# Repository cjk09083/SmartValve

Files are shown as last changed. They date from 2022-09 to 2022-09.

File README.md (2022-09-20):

# SmartValve
<div>





</div>

## LoRa 통신기반 자가발전형 원격 수로 모니터링 시스템

<div align="center">
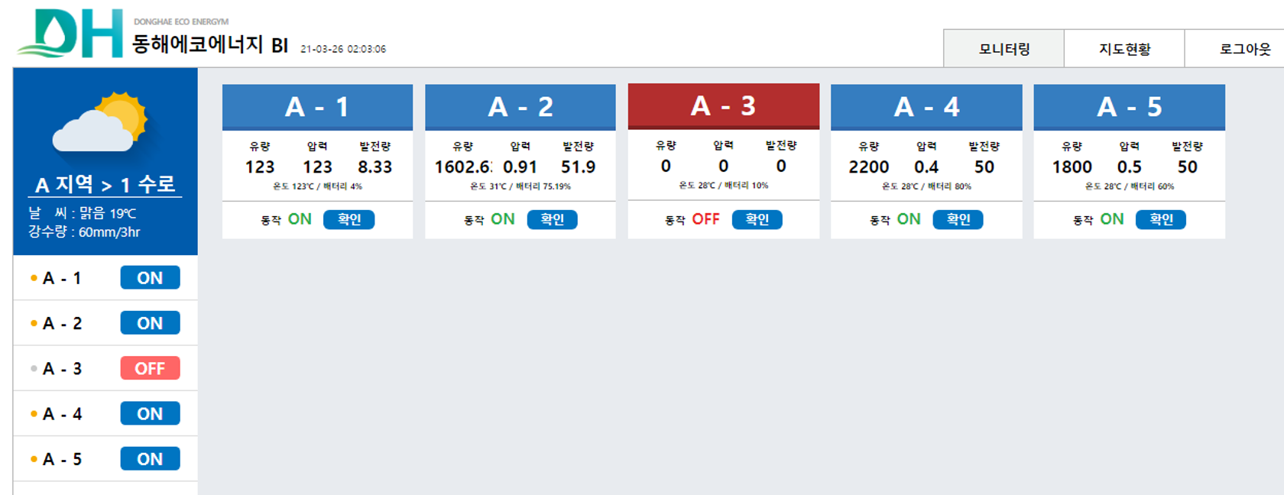
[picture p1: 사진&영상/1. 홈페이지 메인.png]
&nbsp;  
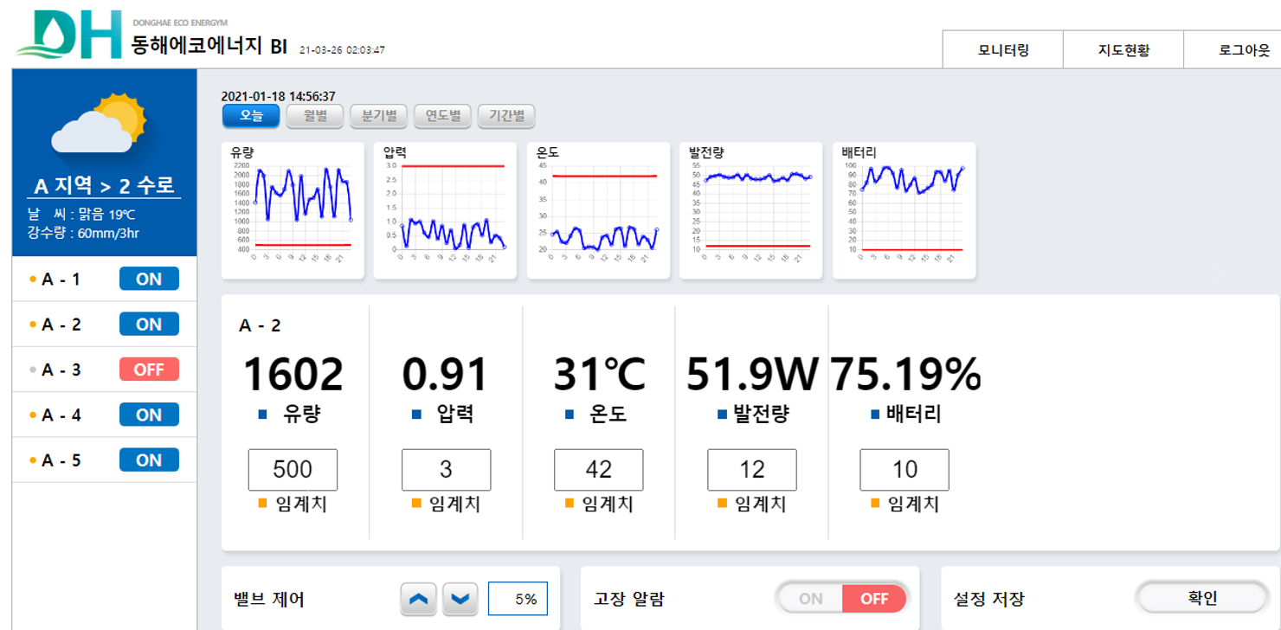
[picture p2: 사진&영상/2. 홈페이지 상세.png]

</div></br>

## 목적
- 수로에 흐르는 물을 이용해 자가발전 
- 수로와 사무실간의 LoRa를 이용한 무선통신을 연결하고 데이터 송수신 하는 시스템 
- 수로의 상태를 홈페이지에서 모니터링하고 홈페이지에서 수로를 원격 제어

## 담당 
- 모니터링 홈페이지 (HTML, PHP, JavaScript)  
- 아두이노의 수로 모터 제어와 센서링 정보 무선 통신 (LoRa, WiFi)
- KC 인증 (전자파적합성인증 - 한국전자통신연구원)
- 소수력 발전을 위한 충방전 회로 설계 

## 기능

### 1. 수로에서 흐르는 물로 발전기를 돌려 아두이노와 센서들을 동작시킬 전력 충전
 - 수로 내에 수차와 발전기를 연결, 발생하는 전력을 변환하여 배터리에 충전
<div align="center">
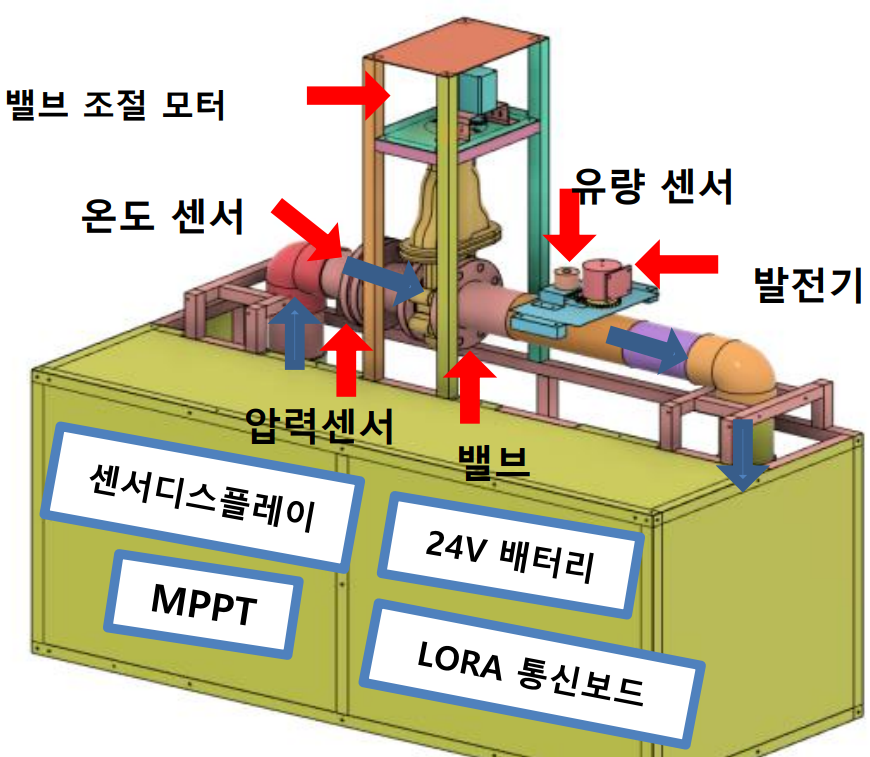
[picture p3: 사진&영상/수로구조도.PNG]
&nbsp;  
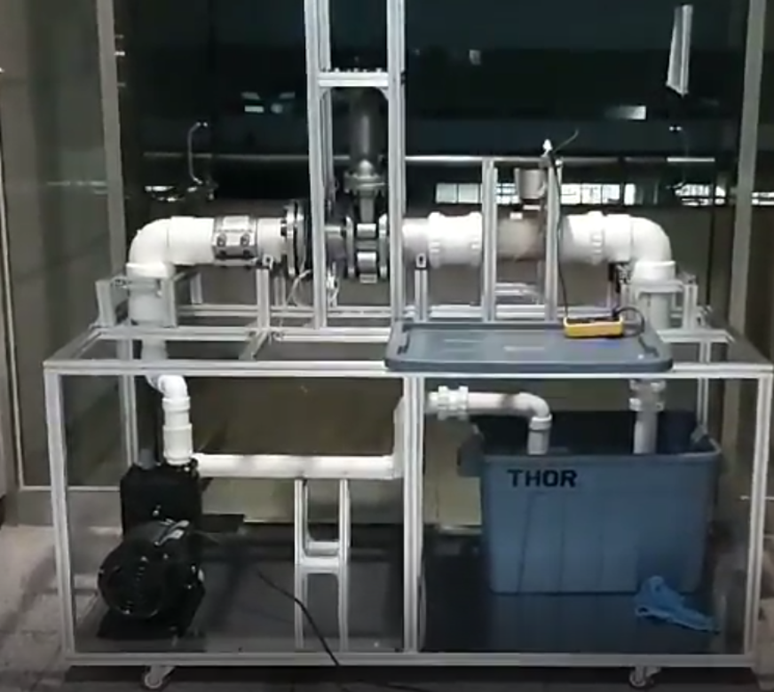
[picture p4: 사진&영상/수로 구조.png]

</div></br>

### 2. 수로에서 측정한 정보를 서버와 연동
 - 수로에 설치된 아두이노와 사무실에 설치된 아두이노간의 LoRa 통신 연결 (무자격으로 사용 가능한 923.1MHz 대역 사용)
 - 사무실에 설치된 아두이노에서 서버로 정보 업로드 (Wifi HTTP)
 - 홈페이지에서 밸브 OPEN량을 0~100%로 조절하면 통신이 역순으로 수로에 도달해 수로의 수문에 달린 모터 제어 
 
영상) 수로 밸브를 50%-> 1% 로 제어 (사진&영상/밸브 제어 50 to 1.mp4)
<div align="center">

</div></br>

### KC 인증 (전자파적합성인증) - 제어보드 / 전자파테스트 / 충격테스트
<div align="center">
 &nbsp;  
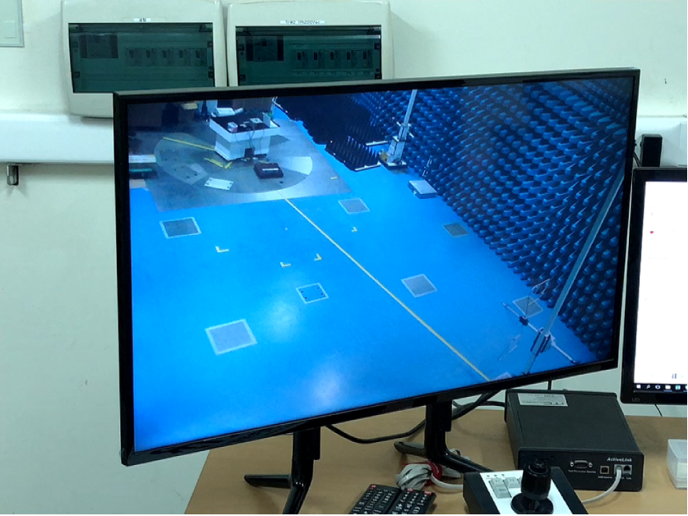
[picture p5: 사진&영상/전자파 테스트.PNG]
&nbsp;  
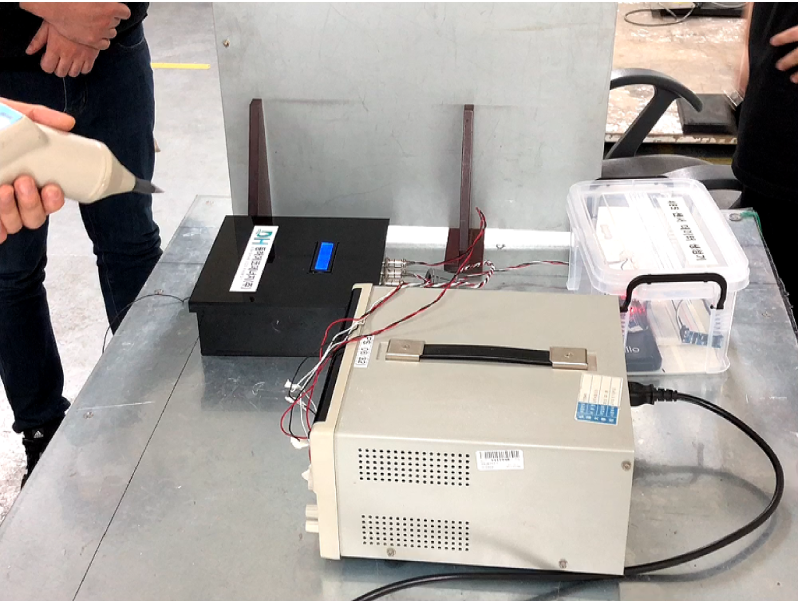
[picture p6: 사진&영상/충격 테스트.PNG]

</div></br>

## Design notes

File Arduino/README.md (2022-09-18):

# Arduino 파일 설명

485_gen : (아두이노 우노) 485 센서 데이터 생성기, 5초 간격으로 3개의 값이 순환변경됨

Nano_suro : (아두이노 나노) 전압센서를 통해 측정한 발전량, 배터리량을 Lora 보드에게 전송해줌

LoRa_Gateway : (Lora32) 사무실에 설치되는 Lora 게이트웨이, wifi사용

LoRa_suro : (Lora32) 수로에 설치되는 제품속 Lora 단말기, KC인증 대상

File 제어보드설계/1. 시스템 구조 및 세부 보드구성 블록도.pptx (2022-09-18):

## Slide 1

시스템 블록도

모터

모터 드라이버

USER

SERVER

배터리

WIFI

WIFI

수로

NANO

LORA

센서
(온도/유량/압력)

LCD

GATE
WAY

Raspberry Pi
(고장 진단)

LORA 통신

RS-485 통신

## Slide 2

보드 블록도

수로 발전기

GND

MPPT

GND

태양광 발전기

3상 컨버터

A상

B상

C상

릴레이

릴레이

전압 센서

GND

5V

GND

GND

5V

LORA board

발전량

GND

24V

Motor driver

배터리

컨버터

5V

GND

5V

회전 방향

펄스

GND

전압 센서

GND

RX

TX

RS485 to
UART

GND

A

B

압력 센서

GND

GND

유량 센서

GND

5V

Arduino nano board

온도 센서

발전량

배터리 잔량

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
3.3V

20~24V

배터리 잔량

배터리

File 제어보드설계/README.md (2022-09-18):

# 시스템 구조

## 시스템 블록도
<div align="center">
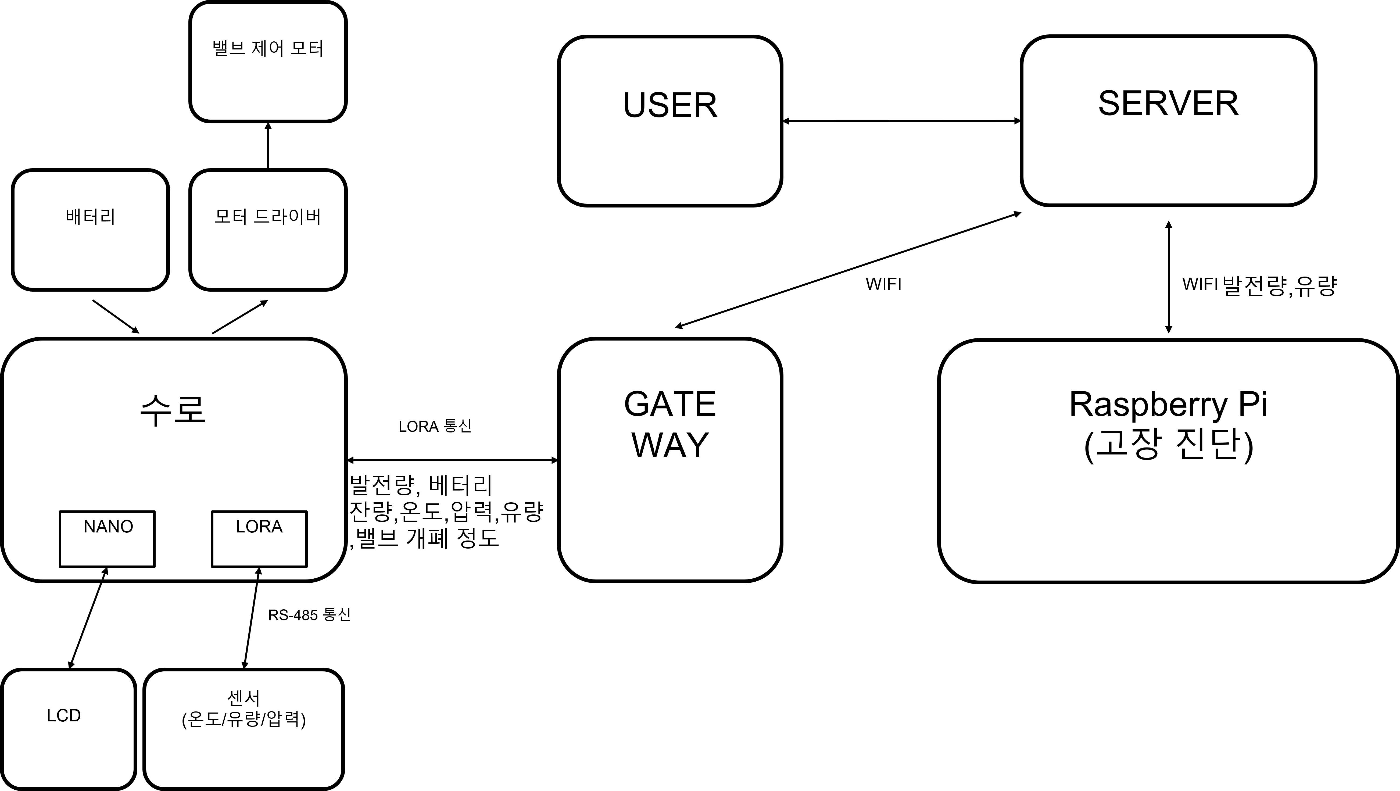
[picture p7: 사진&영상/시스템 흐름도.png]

</div></br>

1. 수로의 메인보드와 게이트웨이는 동일한 LoRa 통신 보드를 사용하여 통신한다.

2. 수로에서 게이트웨이로 온도&유량&압력 센서값과 배터리잔량, 발전량, 밸브값(닫힌 정도)을 전송한다. </br>
  게이트웨이에서는 USER가 조작한 밸브 제어명령을 수로에 전송한다.
  
3. 게이트웨이는 각 수로에서 모인 수로 데이터를 WiFi 통신으로 서버에 축적한다.

4. 라즈베리파이 보드는 일정 시간마다 서버에서 수로 데이터를 가져와 인공지능 고장 진단을 수행하고 진단 결과를 다시 서버에 전송한다.

5. 유저는 홈페이지 GUI 형태로 서버에 축적된 데이터를 확인하고 필요해 각 수로의 밸브값을 제어할 수 있다.

## 보드 블록도
<div align="center">
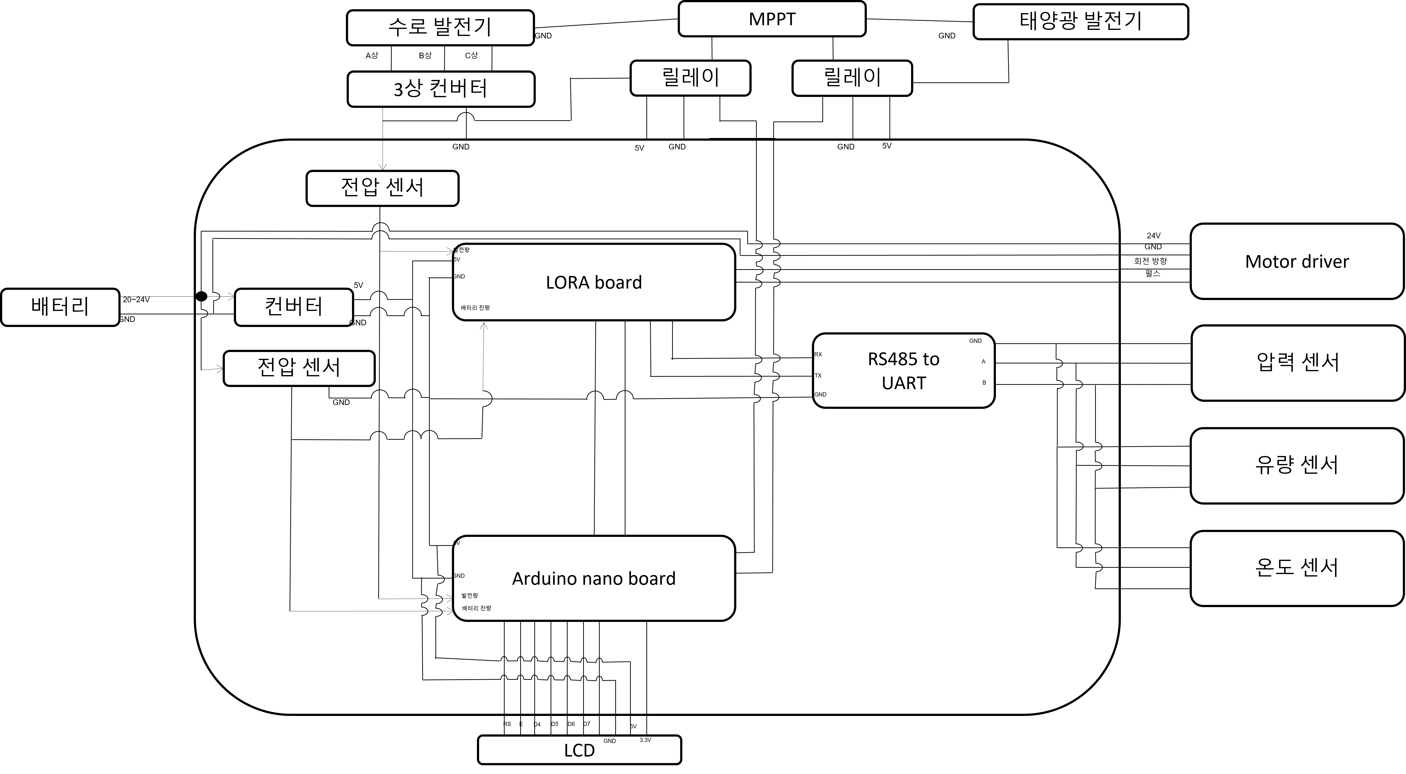
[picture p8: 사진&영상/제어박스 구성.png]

</div></br>

1. 배터리(20~24V)의 전압이 모터드라이브에 공급되고 컨버터를 통해 5V로 다운되어 Nano 보드와 LoRa 보드에 공급된다. 

2. 보드의 LoRa보드에서 RS485통신을 통해 압력&유량&온도 센서값을 가져오고 수로 발전기의 발생 전압과 배터리 전압을 전압센서를 통해 가져온다. </br>
  이후 수집한 센서값과 전압값을 LoRa통신 안테나를 통해 게이트웨이 LoRa보드에게 전송한다.
  
3. Nano 보드는 전압센서을 통해 측정한 배터리 잔량과 발전량을 가져와 LCD 디스플레이에 출력한다. </br>
  또한 릴레이 모듈을 제어하여 수로 발전기가 동작할때는 수로 발전기와 배터리를 연결하고 그 외에는 태양광 발전기와 배터리를 연결하여 배터리를 충전시킨다.
  
4. 게이트웨이에서 밸브 제어 명령이 도착할 경우 LoRa보드에서 현재의 밸브값과 제어 명령이 지령하는 밸브값을 비교하여 필요한 횟수만큼 스텝모터를 회전시킨다.

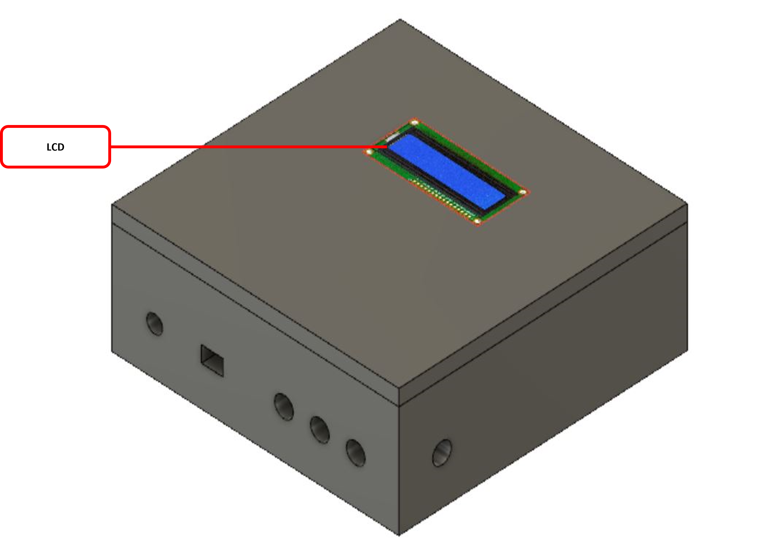
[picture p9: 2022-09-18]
사진&영상/제어박스 외부.png

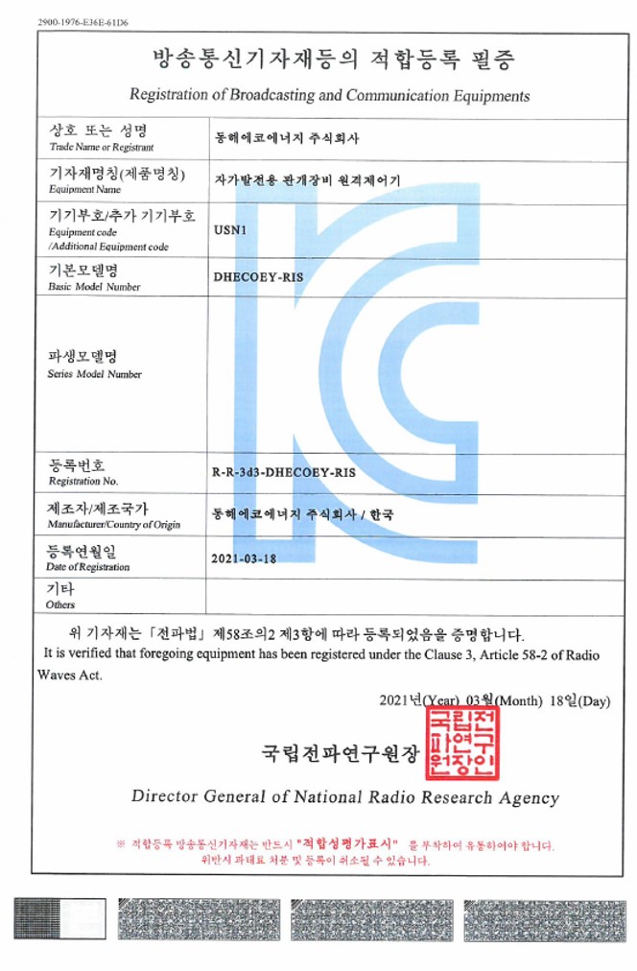
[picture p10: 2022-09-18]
사진&영상/수로 KC 인증.jpg

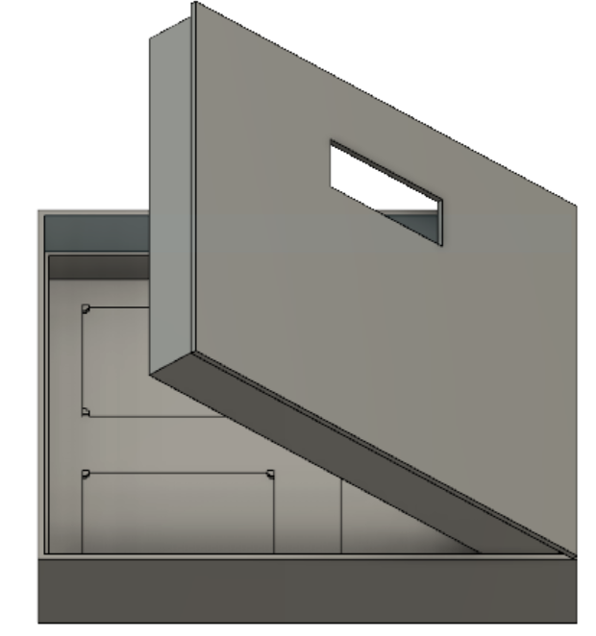
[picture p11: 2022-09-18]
제어보드설계/3. 보드 케이스 3D 디자인/2 전면부 OPEN시 (측면부 커넥터 부분 디자인은 미정).png

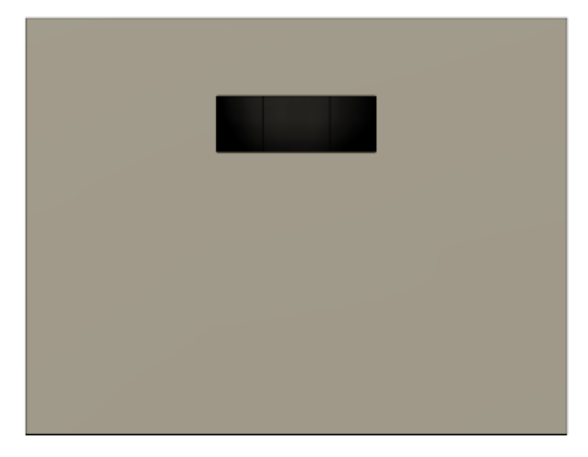
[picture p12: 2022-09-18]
제어보드설계/3. 보드 케이스 3D 디자인/1 전면부(구멍에는 LCD).png

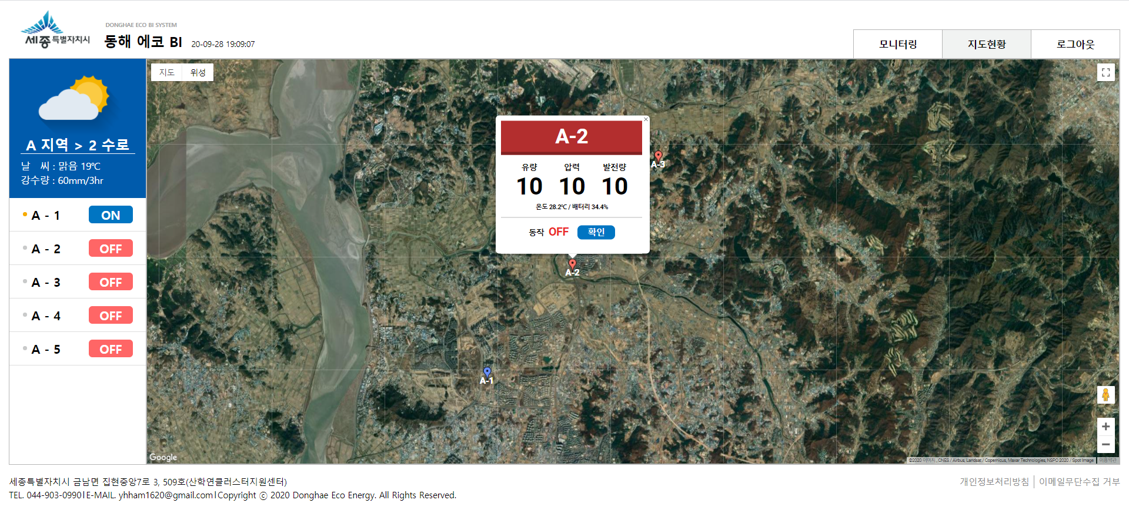
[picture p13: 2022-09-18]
사진&영상/3. 홈페이지 지도.png

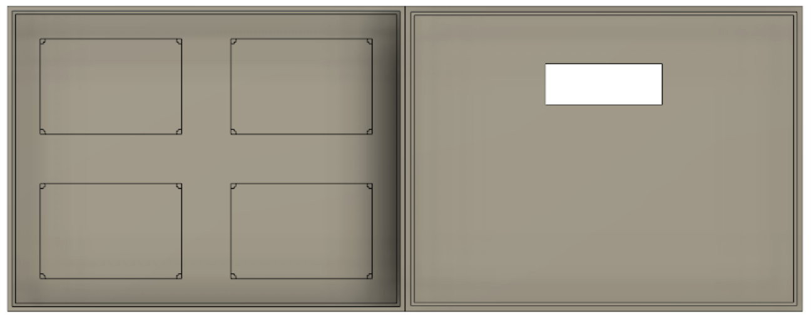
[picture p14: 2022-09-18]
제어보드설계/3. 보드 케이스 3D 디자인/3 아랫부분과 윗부분 나란히 (빵판 4개를 간격을 두고 배치).png

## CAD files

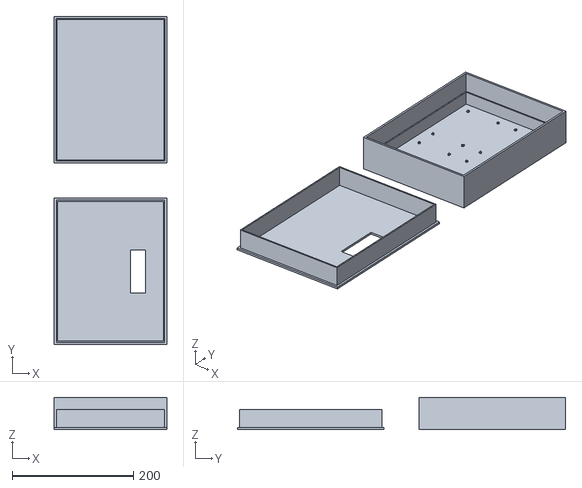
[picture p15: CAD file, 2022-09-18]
제어보드설계/3. 보드 케이스 3D 디자인/케이스 도면.stl
186.0 x 542.0 x 53.0

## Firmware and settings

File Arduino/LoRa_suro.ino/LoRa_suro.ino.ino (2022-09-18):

//백업용 파일 20210307//
#include <SPI.h>
#include <LoRa.h>
#include <Wire.h>  
#include "SSD1306.h" 
#include <EEPROM.h>
#include <LiquidCrystal_I2C.h>

#define SCK     5    // GPIO5  -- SX1278's SCK
#define MISO    19   // GPIO19 -- SX1278's MISnO
#define MOSI    27   // GPIO27 -- SX1278's MOSI
#define SS      18   // GPIO18 -- SX1278's CS
#define RST     14   // GPIO14 -- SX1278's RESET
#define DI0     26   // GPIO26 -- SX1278's IRQ(Interrupt Request)
#define BAND  923100000 // 923.1 MHz

#define ENA     23   // GPIO21 -- Valve ENA
#define DIR     12   // GPIO12 -- Valve DIR
#define PUL     13   // GPIO13 -- Valve PUL

//#define TRIG    25   // GPIO39 -- sonic TRIG
//#define ECHO    34   // GPIO38 -- sonic ECHO

//#define PIN_SDA 21
//#define PIN_SCL 22

#define PIN_BAT 34
#define PIN_CHA 35

uint8_t T[] = {0x03, 0x04, 0x03, 0xE8, 0x00, 0x02, 0xF0, 0x59};
uint8_t P[] = {0x01, 0x04, 0x00, 0x00, 0x00, 0x02, 0x71, 0xCB};
uint8_t F[] = {0x02, 0x04, 0x03, 0xE9, 0x00, 0x02, 0xA0, 0x48};


//uint8_t T[] = {0x03};

int data[10];

unsigned long total_step = 48 * 50 * 80; // 48바퀴 * * 80스텝?
unsigned long full_step = 48 * 5000 * 80;

int step_du = 15;           // 펄스 길이 [us]
int step_delay = 15;
        
int id = 1;
unsigned long counter = 0;
unsigned int send_flag = 0;
long mot_step = 0;

int close_dir = 1; //명령어 d가 닫기, a가 열기
int open_dir = 0;

unsigned long ctn_ms = 0;
int   mot_dir = 1, mot_ena = 0;
double valve_data = 0;
float temp = 0, pressure = 0, flow = 0, distance=0, bat = 0, charge = 0;
float temp_total = 0, pressure_total = 0, flow_total = 0, bat_total = 0, charge_total = 0;

//SSD1306 display(0x3c, 21, 22);
String rssi = "RSSI --";
String packSize = "--";
String packet ;
String mot_data = "Valve stop";
//==================================================
//OLED pins to ESP32 GPIOs via this connecthin:
//OLED_SDA -- GPIO4
//OLED_SCL -- GPIO15
//OLED_RST -- GPIO16

SSD1306  display(0x3c, 4, 15);
//HardwareSerial Serial2(2);
LiquidCrystal_I2C lcd(0x27,16,2);  // set the LCD address to 0x27 for a 16 chars and 2 line display



////////////////////////////////////////
/////////// functions///////////////////
////////////////////////////////////////
void drawFontFaceDemo();
String readSerial();
String readSerial2();
void cbk(int packetSize);
void DisplaySetup();
void ValveSetup();
void break_str(String str);
float checkT();
float checkP();
float checkF();
float checkB();
float checkC();
void lcd_set();   //lcd 값 세팅 

float wire_arduino();


////////////////////////////////////////
/////////// setup & loop ///////////////
////////////////////////////////////////

void setup() {
  if(id==1){
    total_step = 1 * 50 * 80; // 48바퀴 * * 80스텝?
    full_step = 1 *5000 * 80;
    step_du = 20;
    step_delay = 50;
  }
  //DisplaySetup();
  ValveSetup();
//  pinMode(ENA, OUTPUT);
  pinMode(DIR, OUTPUT);
  pinMode(PUL, OUTPUT);

  Wire.begin();
  lcd.init();                      // initialize the lcd 
  lcd.backlight();
  lcd_set();
  Serial.begin(9600);
//  Serial2.begin(9600);

  //Serial1.begin(9600,SERIAL_8N1, 22, 36); //Baud rate, parity mode, RX, TX
  Serial2.begin(9600,SERIAL_8N1, 23, 17); //Baud rate, parity mode, RX, TX

//  while (!Serial);
  Serial.println();
  Serial.println("LoRa Sender Test");
  
  SPI.begin(SCK,MISO,MOSI,SS);
  LoRa.setPins(SS,RST,DI0);
  if (!LoRa.begin(BAND)) {
    Serial.println("Starting LoRa failed!");
    while (1);
  }
  LoRa.setTxPower(14);

  //LoRa.onReceive(cbk);
//  EEPROM.write(10, 10);
//  EEPROM.commit();

  EEPROM.begin (255);
//  EEPROM.write(1, 4);
  delay(10);
  valve_data = EEPROM.read(1);
  mot_step = valve_data * full_step / 100;
  Serial.print("Init Valve : ");
  Serial.println(valve_data);
  Serial.print(", Steps : ");
  Serial.println(mot_step);
  LoRa.receive();
  
  Serial.println("init ok");

}


void loop() {
  int packetSize = LoRa.parsePacket();
  if (packetSize) { cbk(packetSize);  }

  String str;
  if (Serial.available()){
    str = readSerial();   
    Serial.println(str); 
    break_str(str);   
  }
  
//  if (Serial2.available()){
//    readSerial2();  
//  }
  
  if(ctn_ms++> 100){
    send_flag++;
       
    digitalWrite(DIR, mot_dir);    
    Serial.print("Valve DIR : ");
    Serial.println(mot_dir);
//    digitalWrite(ENA, HIGH);
    mot_ena = 0;  

    temp = checkT();
    temp_total += temp;
    delay(10);
    pressure = checkP();
    pressure_total += pressure;
    delay(10);
    flow = checkF();
    flow_total += flow;
    Serial.print("Temp : ");
    Serial.print(temp);
    Serial.print("(");
    Serial.print(temp_total/send_flag);

    Serial.print("), Pressure : ");
    Serial.print(pressure);
    Serial.print("(");
    Serial.print(pressure_total/send_flag);
    
    Serial.print("), Flow : ");
    Serial.print(flow);
    Serial.print("(");
    Serial.print(flow_total/send_flag);
    Serial.println(")");

    valve_data = mot_step * 100 / full_step;
    Serial.print("Valve : ");
    Serial.print(valve_data);
    EEPROM.write(1, valve_data);
    EEPROM.commit();

    wire_arduino();
    
    //bat = checkB();
    bat_total += bat;
    Serial.print(", Battery : ");
    Serial.print(bat);
    Serial.print("(");
    Serial.print(bat_total/send_flag);
    
    //charge = checkC(); 
    charge_total += charge;
    Serial.print("), Charge : ");
    Serial.print(charge);
    Serial.print("(");
    Serial.print(charge_total/send_flag);
    Serial.print(") ");
    
    lcd_set();
    
    // send packet
    if (send_flag > 3){
      lcd.init();
      lcd_set();
      temp = temp_total / send_flag;
      pressure = pressure_total / send_flag;
      flow = flow_total / send_flag;
      bat = bat_total / send_flag;
      charge = charge_total / send_flag;
      String senddata = "d"+String(id)+"c"+String(counter)+"t"+String(temp)
      +"p"+String(pressure)+"f"+String(flow)+"v"+String(valve_data)+"b"+String(bat)+"h"+String(charge)+"e";
      LoRa.beginPacket();  
      LoRa.print(senddata);
      LoRa.endPacket();
      
      Serial.print("Send : ");
      Serial.println(senddata);
      //drawFontFaceDemo();     
      temp_total = 0; pressure_total = 0; flow_total = 0; bat_total = 0; charge_total = 0;
      counter++; 
      send_flag = 0;        
    } else {  
      Serial.print("Send_flag : ");
      Serial.println(send_flag);
    }
    ctn_ms=0;
  }

  ctn_ms++;
//  Serial.println(ctn_ms);
  
  delay(1);                       

}


///////////////////////////////////// ///
/////////// functions///////////////////
////////////////////////////////////////
void break_str(String str){
  
  if (str.startsWith("a")) {       
      Serial.println("Valve close");   
      mot_data = "Valve close";
      mot_dir = close_dir;  
      mot_ena = 1;
      digitalWrite(DIR, mot_dir); 
      Serial.print("Valve Dir :");   
      Serial.println(mot_dir);   
      delay(100);
//      digitalWrite(ENA, LOW);  
      delay(10);
      for (int i = 0; i < total_step; i++){
        digitalWrite(PUL, HIGH);    
        delayMicroseconds(step_du);                     
        digitalWrite(PUL, LOW);    
        delayMicroseconds(step_delay);  
      }
      mot_step -= total_step;
      valve_data = mot_step * 100 / full_step;
      Serial.print("Valve : ");
      Serial.print(valve_data); 
      Serial.println(" Turn end");       
      EEPROM.write(1, valve_data);
      EEPROM.commit();
      delay(10);
//      digitalWrite(ENA, HIGH);  
      ctn_ms = 0;
    } else if (str.startsWith("d"))  {   
      Serial.println("Valve open");  
      mot_data = "Valve open"; 
      mot_dir = open_dir;
      mot_ena = 1;
      digitalWrite(DIR, mot_dir);  
      Serial.print("Valve Dir :");   
      Serial.println(mot_dir);    
      delay(100);
//      digitalWrite(ENA, LOW);  
      delay(10);
      for (int i = 0; i < total_step; i++){
        digitalWrite(PUL, HIGH);    
        delayMicroseconds(step_du);                     
        digitalWrite(PUL, LOW);    
        delayMicroseconds(step_delay);  
      }
      mot_step += total_step;
      valve_data = mot_step * 100 / full_step;
      Serial.print("Valve : ");
      Serial.print(valve_data); 
      Serial.println(" Turn end"); 
      EEPROM.write(1, valve_data);
      EEPROM.commit();
      delay(10);
//      digitalWrite(ENA, HIGH);  
      ctn_ms = 0;
    } else if (str.startsWith("s"))  {   
      Serial.println("Valve stop");
      mot_data = "Valve stop";   
      EEPROM.write(1, mot_step);
      EEPROM.commit();
//      digitalWrite(ENA, HIGH);
      mot_ena = 0;  
      mot_step = 0;
    } else if (str.startsWith("p"))  {   
        int diff_value = 5;
        Serial.println("Valve close");  
        mot_data = "Valve close"; 
        mot_dir = close_dir;
        mot_ena = 1;
        digitalWrite(DIR, mot_dir);  
        Serial.print("Valve Dir :");   
        Serial.println(mot_dir);   
        Serial.print("Need turns :");   
        Serial.println(diff_value);  
        delay(100);
//        digitalWrite(ENA, LOW);  
        delay(10);
        for (int i = 0; i < diff_value; i++){
         for (int j = 0; j < total_step; j++){
            digitalWrite(PUL, HIGH);    
            delayMicroseconds(step_du);                     
            digitalWrite(PUL, LOW);    
            delayMicroseconds(step_delay);  
          }
          mot_step += total_step;
          valve_data = mot_step * 100 / full_step;
          Serial.print("mot_step : ");   
          Serial.print(mot_step);
          Serial.print(", Valve1 : ");   
          Serial.println(valve_data);
        }
        Serial.println("Turn end");  
        EEPROM.write(1, valve_data);
        EEPROM.commit();
        delay(10);
//        digitalWrite(ENA, HIGH);  
        ctn_ms = 0;
  }
  
}

void drawFontFaceDemo() {
    display.clear();
    String s="ID:"+String(id)+" Send: ";
    s=s+counter;
    String sen = "T:"+String(int(temp))
    +" P:"+String(int(pressure))+" F:"+String(int(flow));
    display.drawString(0, 0, s);
    display.drawString(0, 20, mot_data);
    display.drawString(0, 40, sen);
    display.display();
}

String readSerial(){   
   String str = "";   
   char ch;   
    while( Serial.available() > 0 )   
    {   
      ch = Serial.read();   
      str.concat(ch);   
      delay(10);  
    }   
    return str;     
}   


String readSerial2(){   
   String str = "";   
   char ch;   
   int ct = 0;
   Serial.print("Recived : "); 
    while( Serial2.available() > 0 )   
    {   
      ch = Serial2.read();   
      str.concat(ch);
      Serial.print(" "); 
      Serial.print(ch,HEX); 
      data[ct] = (int) ch; 
      if(data[ct] < 0){
        data[ct] = 256 - (int)(0xFFFFFF - ch);
       }
      ct++;
      delay(10);  
    }   
    Serial.println();
    return str;     
}   


void cbk(int packetSize) {
  packet ="";
  packSize = String(packetSize,DEC);

  for (int i = 0; i < packetSize; i++) { packet += (char) LoRa.read(); }

  if (packet.startsWith("u")){       
    Serial.println("Valve open");   
    mot_data = "Valve open";
    mot_dir = open_dir;  
    mot_ena = 1;
    digitalWrite(DIR, mot_dir); 
    Serial.print("Valve Dir :");   
    Serial.println(mot_dir);   
    delay(100);
//    digitalWrite(ENA, LOW);  
    delay(10);
    for (int i = 0; i < total_step; i++){
      digitalWrite(PUL, HIGH);    
      delayMicroseconds(step_du);                     
      digitalWrite(PUL, LOW);    
      delayMicroseconds(step_delay);  
    }
    mot_step -= total_step;
    valve_data = mot_step * 100 / full_step;
    Serial.print("Valve : ");
    Serial.print(valve_data);
    Serial.println("Turn end");  
    EEPROM.write(1, valve_data);
    EEPROM.commit();
    delay(10);
//    digitalWrite(ENA, HIGH);  
    ctn_ms = 0;   
  } else if (packet.startsWith("d"))  {   
    Serial.println("Valve close");  
    mot_data = "Valve close"; 
    mot_dir = close_dir;
    mot_ena = 1;
    digitalWrite(DIR, mot_dir);  
    Serial.print("Valve Dir :");   
    Serial.println(mot_dir);    
    delay(100);
//    digitalWrite(ENA, LOW);  
    delay(10);
    for (int i = 0; i < total_step; i++){
      digitalWrite(PUL, HIGH);    
      delayMicroseconds(step_du);                     
      digitalWrite(PUL, LOW);    
      delayMicroseconds(step_delay);  
    }
    mot_step += total_step;
   
    valve_data = mot_step * 100 / full_step;
    Serial.print("Valve : ");
    Serial.print(valve_data);
    Serial.println("Turn end");  
    EEPROM.write(1, valve_data);
    EEPROM.commit();
    delay(10);
//    digitalWrite(ENA, HIGH);  
    ctn_ms = 0;
  } else if (packet.startsWith("s"))  {   
    Serial.println("Valve stop");   
    mot_data = "Valve stop";
//    digitalWrite(ENA, HIGH);    
    
    valve_data = mot_step * 100 / full_step;
    Serial.print("Valve : ");
    Serial.print(valve_data);
    EEPROM.write(1, valve_data);
    EEPROM.commit();
    mot_ena = 0;
    mot_step = 0;
  } else if (packet.startsWith("t"))  {   
    int id_index = packet.indexOf("/");
    int valve_index = packet.indexOf("/",id_index+1);
    String id_str = packet.substring(id_index+1,valve_index); 
    String valve_str = packet.substring(valve_index+1); 
    int turn_id = id_str.toInt();
    int turn_valve = valve_str.toInt();
    if (turn_valve > 100){
      turn_valve = 100;
    }
    Serial.print("turn id : ");
    Serial.print(turn_id);
    Serial.print(", valve : ");
    Serial.println(turn_valve);
   
    if(turn_id == id){      
      Serial.print("It's me!!! turn valve to ");
      Serial.println(turn_valve);

      if(turn_valve > valve_data){
        int diff_value = turn_valve - valve_data;
        Serial.println("Valve close");  
        mot_data = "Valve close"; 
        mot_dir = close_dir;
        mot_ena = 1;
        digitalWrite(DIR, mot_dir);  
        Serial.print("Valve Dir :");   
        Serial.println(mot_dir);   
        Serial.print("Need turns :");   
        Serial.println(diff_value);  
        delay(100);
//        digitalWrite(ENA, LOW);  
        delay(10);
        for (int i = 0; i < diff_value; i++){
         for (int j = 0; j < total_step; j++){
            digitalWrite(PUL, HIGH);    
            delayMicroseconds(step_du);                     
            digitalWrite(PUL, LOW);    
            delayMicroseconds(step_delay);  
            mot_step += 1;
          }
          valve_data = mot_step * 100 / full_step;
          Serial.print("mot_step : ");   
          Serial.print(mot_step);
          Serial.print(", Valve1 : ");   
          Serial.println(valve_data);
        }
        Serial.println("Turn end");  
        EEPROM.write(1, valve_data);
        EEPROM.commit();
        delay(10);
//        digitalWrite(ENA, HIGH);  
        ctn_ms = 0;
      } else if (turn_valve < valve_data){
        int diff_value = valve_data - turn_valve;
        Serial.println("Valve open");   
        mot_data = "Valve open";
        mot_dir = open_dir;  
        mot_ena = 1;
        digitalWrite(DIR, mot_dir); 
        Serial.print("Valve Dir :");   
        Serial.println(mot_dir);   
        Serial.print("Need turns :");   
        Serial.println(diff_value); 
        delay(100);
//        digitalWrite(ENA, LOW);  
        delay(10);
        
        for (int i = 0; i < diff_value; i++){
         for (int j = 0; j < total_step; j++){
            digitalWrite(PUL, HIGH);    
            delayMicroseconds(step_du);                     
            digitalWrite(PUL, LOW);    
            delayMicroseconds(step_delay);  
            mot_step -= 1;
          }
          valve_data = mot_step * 100 / full_step;
          Serial.print("mot_step : ");   
          Serial.print(mot_step);
          Serial.print(", Valve1 : ");   
          Serial.println(valve_data);
        }
        Serial.println("Turn end");  
        EEPROM.write(1, valve_data);
        EEPROM.commit();
        
        delay(10);
//        digitalWrite(ENA, HIGH);  
        ctn_ms = 0;
        
      } else {
        
      Serial.println("No need turn");   
      }
      
    } 
    
  } 
  
  Serial.println("packet : "+packet);
//  display.drawString(0, 60, packet);
//  display.display();
}


void DisplaySetup() {
  pinMode(16,OUTPUT);
  digitalWrite(16, LOW);    // set GPIO16 low to reset OLED
  delay(50); 
  digitalWrite(16, HIGH); // while OLED is running, must set GPIO16 in high
  // Initialising the UI will init the display too.
  display.init();
  display.flipScreenVertically();
  display.setFont(ArialMT_Plain_16);
  display.setTextAlignment(TEXT_ALIGN_LEFT);
}

void ValveSetup() {
//  pinMode(ENA, OUTPUT);
  pinMode(DIR, OUTPUT);
  pinMode(PUL, OUTPUT);
//  digitalWrite(ENA, HIGH);    
  digitalWrite(DIR, mot_dir);    
  digitalWrite(PUL, HIGH);    
}


float checkT(){
  Serial.print("Send T : ");
  int sizeofT = sizeof(T);
  for (int i = 0; i < sizeofT; i++) {
    Serial.print(T[i],HEX);
    Serial2.write(T[i]);
  }
  Serial.println();  
  delay(100);
  readSerial2();

  float new_data = (data[3]*256 + data[4])/pow(10,data[6]);
  return new_data;
}

float checkP(){
  Serial.print("Send P : ");
  int sizeofP = sizeof(P);
  for (int i = 0; i < sizeofP; i++) {
    Serial.print(P[i],HEX);
    Serial2.write(P[i]);
  }
  Serial.println();  
  delay(100);
  readSerial2();
  //    (int(data[3])*(16^2)+int(data[4) )/ (10^(int(data[5]*16^2)+int(data[6])))
  float new_data = (data[3]*256 + data[4])/pow(10,data[6]);
  return new_data;
}

float checkF(){
  Serial.print("Send F : ");
  int sizeofF = sizeof(F);
  for (int i = 0; i < sizeofF; i++) {
    Serial.print(F[i],HEX);
    Serial2.write(F[i]);
  }
  Serial.println();  
  delay(100);
  readSerial2();
  float new_data = (data[3]*256 + data[4])/pow(10,data[6]);
  return new_data;
}

float checkB(){
  int analog_value=analogRead(PIN_BAT);
  long volt=analog_value*(5*3.47*2);
  float volt2=(volt/4095.0);

  float B_data=(1-((4-(volt2-16))/4))*100;
//  Serial.print("B(");
//  Serial.print(volt2);
//  Serial.print("/");
//  Serial.print(B_data);
//  Serial.print(")");
  if (B_data <0){
    B_data = 0.1;  
  } else if (B_data > 100){
    B_data = 99.9;  
  }
  return B_data;
}

float checkC(){
  int sensorValue = analogRead(PIN_CHA);  
  long Volt = sensorValue*(5*3.3*2);
  float c_value = (Volt/4095.0);

 
  return c_value;
}


float wire_arduino(){
  int a[10];
  int i=0, sum=0, sum2=0;
  Wire.requestFrom(1,9);
  while(Wire.available()>0){
    a[i] = (int) Wire.read();
    Serial.print(a[i]);
    Serial.print(" ");
    if(a[i] != 255){
      if(i<4){
        sum = int(a[i])*(pow(10,4-i-1))+sum;
      } else if (i > 4){
        sum2 = int(a[i])*(pow(10,8-i))+sum2;
      }
    }
    i++;
  }
  Serial.println();
  Serial.print(sum);
  Serial.print(',');
  Serial.print(sum2);
  Serial.println();
    
  long Volt = sum*4*(5*3.3*2);
//  float c_value = (Volt/4095.0);
  float c_value = sum/10;

  long volt=sum2*4*(5*3.47*2);
  float volt2=(volt/4095.0);

//  float B_data=(1-((4-(volt2-16))/4))*100;
  float B_data=sum2/10;

//  Serial.print("B(");
//  Serial.print(volt2);
//  Serial.print("/");
//  Serial.print(B_data);
//  Serial.print(")");
  if (B_data <0){
    B_data = 0.1;  
  } else if (B_data > 100){
    B_data = 99.9;  
  }
//    Serial.println();
//    Serial.print(c_value);
//    Serial.print(',');
//    Serial.println(B_data);
  if((c_value>0)&&(c_value<2000)){
    charge = c_value;
  }
  if((B_data>0)&&(B_data<2000)){
    bat = B_data;
  }
    
  return c_value, B_data;
}

void lcd_set(){
//  lcd.init(); 
  temp = temp_total / send_flag;
  pressure = pressure_total / send_flag;
  flow = flow_total / send_flag;
  bat = bat_total / send_flag;
  charge = charge_total / send_flag;
  lcd.clear();
  lcd.setCursor(0,0);
  lcd.print("B:");
  lcd.print(bat);
  lcd.print(", C:");
  lcd.print(charge);
  
  lcd.setCursor(0,1);
  lcd.print("S:");
  lcd.print(temp);
  lcd.print("/");
  lcd.print((int)pressure);
  lcd.print("/");
  lcd.print((int)flow);
//  lcd.print("         ");
}

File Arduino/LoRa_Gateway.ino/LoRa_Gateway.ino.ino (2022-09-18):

//백업용 파일 20210307//

#include <SPI.h>
#include <LoRa.h>
#include <Wire.h>  
#include "SSD1306.h" 
#include "images.h"

#include <WiFi.h>
#include <WiFiMulti.h>
#include <HTTPClient.h>

WiFiMulti WiFiMulti;
WiFiClient wificlient;
WiFiClient client2;

//#define ssid "cjk" //wifi id
//#define pass "09083313" 

#define ssid "mernzer1" //wifi id
#define pass "jojo5150"      //wifi pass


#define ssid2 "SK_WiFiGIGA29A8" //wifi id
#define pass2 "1910000928"      //wifi pass1

//#define ssid2 "d109-1_iptime2" //wifi id
//#define pass2 "113333555555"      //wifi pass1

#define SCK     5    // GPIO5  -- SX1278's SCK
#define MISO    19   // GPIO19 -- SX1278's MISO
#define MOSI    27   // GPIO27 -- SX1278's MOSI
#define SS      18   // GPIO18 -- SX1278's CS
#define RST     14   // GPIO14 -- SX1278's RESET
#define DI0     26   // GPIO26 -- SX1278's IRQ(Interrupt Request)
#define BAND    923100000

String id = "2" ;       // 디바이스 id
float temp = 0, presure = 0, flow = 0, charge = 0, bat = 0, valve = 0;
int delay_flag = 0;
int k = 0;
int valve_step = 0;

unsigned int counter = 0;
unsigned int ctn_ms = 0;

String rssi = "RSSI --";
String packSize = "--";
String packet ;

//==================================================
//OLED pins to ESP32 GPIOs via this connecthin:
//OLED_SDA -- GPIO4
//OLED_SCL -- GPIO15
//OLED_RST -- GPIO16
SSD1306  display(0x3c, 4, 15);

////////////////////////////////////////
/////////// functions///////////////////
////////////////////////////////////////

void flag_set();
void drawFontFaceDemo();
void cbk(int packetSize);
String readSerial();
void break_str(String str);
void DisplaySetup();
void WiFisetup();
void wifi_scan();
void Http_post();

void dummy_post();


////////////////////////////////////////
/////////// setup & loop ///////////////
////////////////////////////////////////

void setup() {
  Serial.begin(9600);
  DisplaySetup();
  wifi_scan();
  //WiFisetup();
  
  Serial.println("LoRa Receiver Callback");
  SPI.begin(SCK,MISO,MOSI,SS);
  LoRa.setPins(SS,RST,DI0);  
//  if (!LoRa.begin(923E6)) {
  if (!LoRa.begin(BAND)) {
    Serial.println("Starting LoRa failed!");
    while (1);
  }
  //LoRa.onReceive(cbk);
  LoRa.receive();
//  Serial.println(LoRa.);
  Serial.println("init ok");
}


void loop() {
  int packetSize = LoRa.parsePacket();
  if (packetSize) { cbk(packetSize);  }

String str;
if (Serial.available()){
  str = readSerial();   
  Serial.println(str);   
  break_str(str);
}
 
  flag_set();
}


/////////////////////////////////////////////////////////////////
////////////////////////////////////////////////////////////////


void flag_set() {
  k++;
  if (k >= 99) {
    delay_flag++;
    Serial.print(delay_flag);
    Serial.println(",");
    k = 0;
  }
  delay(10);                      // Wait
}

void drawFontFaceDemo() {
    display.clear();
    display.drawString(0, 0, packet);
    display.drawString(32, 20, rssi); // 들여쓰기, 아래로, 내용
    display.display();
}

void cbk(int packetSize) {
  packet ="";
  packSize = String(packetSize,DEC);
  for (int i = 0; i < packetSize; i++) { packet += (char) LoRa.read(); }
  rssi = "RSSI " + String(LoRa.packetRssi(), DEC) ;
  Serial.println(rssi);
  Serial.println(packet);
  drawFontFaceDemo();

  Serial.println("Send OK");
  for(int i=0; i<3; i++){
    delay(100);
    LoRa.beginPacket();
    LoRa.print("Ok");
    LoRa.endPacket();
  }
  
  if(packet.startsWith("d")){
    postdata(packet);
  }
  
}

String readSerial(){   
   String str = "";   
   char ch;   
    while( Serial.available() > 0 )   
    {   
      ch = Serial.read();   
      str.concat(ch);   
      delay(10);  
    }   

    return str;     
}   

void break_str(String str){

 if (str.startsWith("a"))   
  {       
    Serial.println("motor up");   
    for(int i=0; i<3; i++){
      LoRa.beginPacket();
      LoRa.print("up");
      LoRa.endPacket();
      delay(100);
    }  
  } else if (str.startsWith("d"))  {   
    Serial.println("motor down");   
    for(int i=0; i<3; i++){
      LoRa.beginPacket();
      LoRa.print("down");
      LoRa.endPacket();    
      delay(100);
    }   
  } else if (str.startsWith("s"))  {   
    Serial.println("motor stop");  
    valve_step = 0; 
    for(int i=0; i<3; i++){
      LoRa.beginPacket();
      LoRa.print("stop");
      LoRa.endPacket();    
      delay(100);
    }   
  } else if (str.startsWith("t"))  {   
    dummy_post();
  } 
  
}

void postdata(String strdata){  
    int C_index = strdata.indexOf("c");
    int T_index = strdata.indexOf("t");
    int P_index = strdata.indexOf("p");
    int F_index = strdata.indexOf("f");
    int V_index = strdata.indexOf("v");
    int B_index = strdata.indexOf("b");
    int H_index = strdata.indexOf("h");

    int last_index = strdata.indexOf("e");

    String str_id = strdata.substring(1,C_index);
    String str_temp = strdata.substring(T_index+1,P_index);
    String str_presure = strdata.substring(P_index+1,F_index);
    String str_flow = strdata.substring(F_index+1,V_index);
    String str_valve = strdata.substring(V_index+1,B_index);
    String str_bat = strdata.substring(B_index+1,H_index);
    String str_charge = strdata.substring(H_index+1,last_index);

    Serial.print("ID :  ");
    Serial.print(str_id); 
    Serial.print(", Temp :  ");
    Serial.print(str_temp); 
    Serial.print(", Presure :  ");
    Serial.print(str_presure);
    Serial.print(", Flow :  ");
    Serial.print(str_flow);
    Serial.print(", Valve :  ");
    Serial.print(str_valve);
    Serial.print(", Bat :  ");
    Serial.print(str_bat);
    Serial.print(", Charge :  ");
    Serial.println(str_charge);
    id = str_id;
    temp = str_temp.toFloat();
    presure = str_presure.toFloat();
    flow = str_flow.toFloat();
    valve = str_valve.toFloat();
    bat = str_bat.toFloat();
    charge = str_charge.toFloat();

    //Http_post();
} 

void DisplaySetup() {
  pinMode(16,OUTPUT);
  digitalWrite(16, LOW);    // set GPIO16 low to reset OLED
  delay(50); 
  digitalWrite(16, HIGH); // while OLED is running, must set GPIO16 in high
  // Initialising the UI will init the display too.
  display.init();
  display.flipScreenVertically();
  display.setFont(ArialMT_Plain_16);
  display.setTextAlignment(TEXT_ALIGN_LEFT);
}

void WiFisetup(){
  WiFi.disconnect();
  // Serial.setDebugOutput(true);
  Serial.println();
  Serial.println("[SETUP] Wifi Connecting ");
  //Serial.println(ssid,pass);
  WiFi.mode(WIFI_STA);              // Station 모드로 설정
  WiFiMulti.addAP(ssid, pass);  
  WiFiMulti.addAP(ssid2, pass2);  

  Serial.println();
  Serial.print("Waiting for WiFi... ");
  int wifi_flag = 0;
  while(WiFiMulti.run() != WL_CONNECTED) {
      Serial.print("."); 
      wifi_flag++;
      if(wifi_flag > 5){
        break;
      }
      delay(100);
  }
  Serial.println("");
  Serial.println("WiFi connected");
  Serial.println("IP address: ");
  Serial.println(WiFi.localIP());
  Serial.println(); 
}
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

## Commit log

2022-09-18 kc 인증 파일 삭제
2022-09-18 사진 추가
2022-09-18 보드구조 추가
    [케이스 도면.stl]
2022-09-18 readme 추가
2022-09-18 gif 파일 변경
2022-09-20 수로 기본 동작 영상 추가
